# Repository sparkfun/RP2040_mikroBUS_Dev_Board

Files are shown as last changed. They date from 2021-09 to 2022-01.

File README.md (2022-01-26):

SparkFun RP2040 mikroBUS™ Development Board
========================================

SparkFun RP2040 mikroBUS™ Development Board (https://www.sparkfun.com/products/18721)

[*SparkFun RP2040 mikroBUS™ Development Board (DEV-18721)*](https://www.sparkfun.com/products/18721)

The SparkFun RP2040 mikroBUS™ development board is a low-cost, high performance board with flexible digital interfaces featuring the Raspberry Pi Foundation's RP2040 microcontroller. Besides the Thing Plus or *Feather* footprint (with 18 GPIO pins), the board also includes an SD card slot, 16MB (128Mbit) flash memory, a JST single cell battery connector (with a charging circuit and fuel gauge sensor), an addressable WS2812 RGB LED, JTAG PTH pins, a mikroBUS™ socket, and our signature Qwiic connector.

_The RP2040 is supported with both C/C++ and MicroPython cross-platform development environments, including easy access to runtime debugging. It has UF2 boot and floating-point routines baked into the chip. While the chip has a large amount of internal RAM, the board includes an additional 16MB of external QSPI flash memory to store program code._

_The [mikroBUS™ standard](https://www.mikroe.com/mikrobus) was developed by [MikroElektronika](https://www.mikroe.com/). Similar to our [Qwiic](https://www.sparkfun.com/qwiic) and [MicroMod](https://www.sparkfun.com/micromod) interfaces, mikroBUS™ provides a standardized connection for add-on [Click boards™](https://www.mikroe.com/click-boards) to be hooked up to a microcontroller based development board._

Repository Contents
-------------------

* **/Documentation** - Data sheets, additional product information
* **/Hardware** - Eagle design files (.brd, .sch)

Documentation
--------------

* **[Hookup Guide](https://learn.sparkfun.com/tutorials/2004)** - SparkFun RP2040 mikroBUS™ Development Board
* **[Raspberry Pi RP2040 Datasheet](https://datasheets.raspberrypi.org/rp2040/rp2040_datasheet.pdf)** - Datasheet for the RP2040
* **[SparkFun Graphical Datasheets](https://github.com/sparkfun/Graphical_Datasheets)** - Graphical datasheets for various SparkFun products.

Product Versions
----------------
* [DEV-18721](https://www.sparkfun.com/products/18721) -  initial release

License Information
-------------------

This product is _**open source**_! 

Please review the LICENSE.md file for license information. 

If you have any questions or concerns on licensing, please contact technical support on our [SparkFun forums](https://forum.sparkfun.com/viewforum.php?f=152).

Distributed as-is; no warranty is given.

- Your friends at SparkFun.

_<COLLABORATION CREDIT>_

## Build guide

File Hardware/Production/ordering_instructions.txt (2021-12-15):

panel size, 169x108mm
PCB thickness, 1.6mm
number of layers, 4
soldermask color, Red
silkscreen color, White
oz copper, 1oz
finish, HASL lead free
stencils, top+bottom
pcs per panel, 5
min trace width, 0.1016mm / 0.0040in
min drill size, 0.2000mm / 0.0079in
filename to layer stackup 1/2/3/4: GTL, GL2, GL3, GBL

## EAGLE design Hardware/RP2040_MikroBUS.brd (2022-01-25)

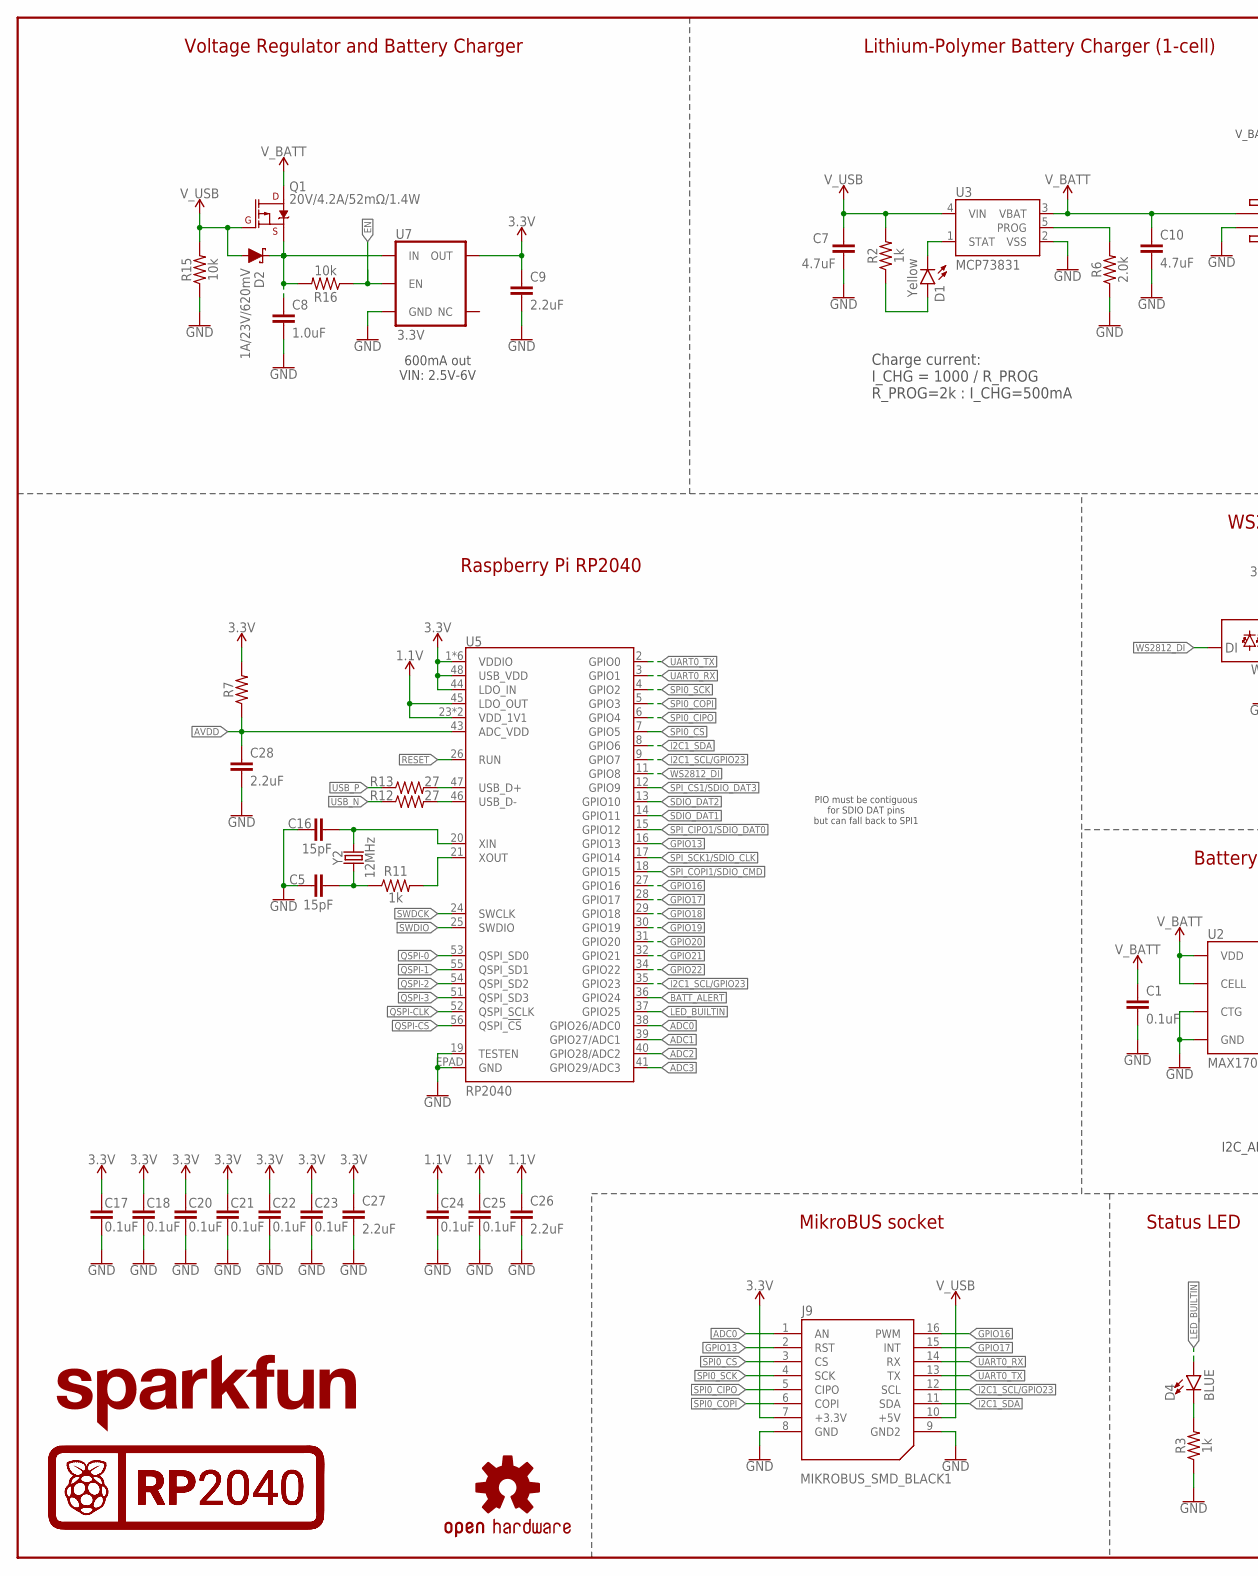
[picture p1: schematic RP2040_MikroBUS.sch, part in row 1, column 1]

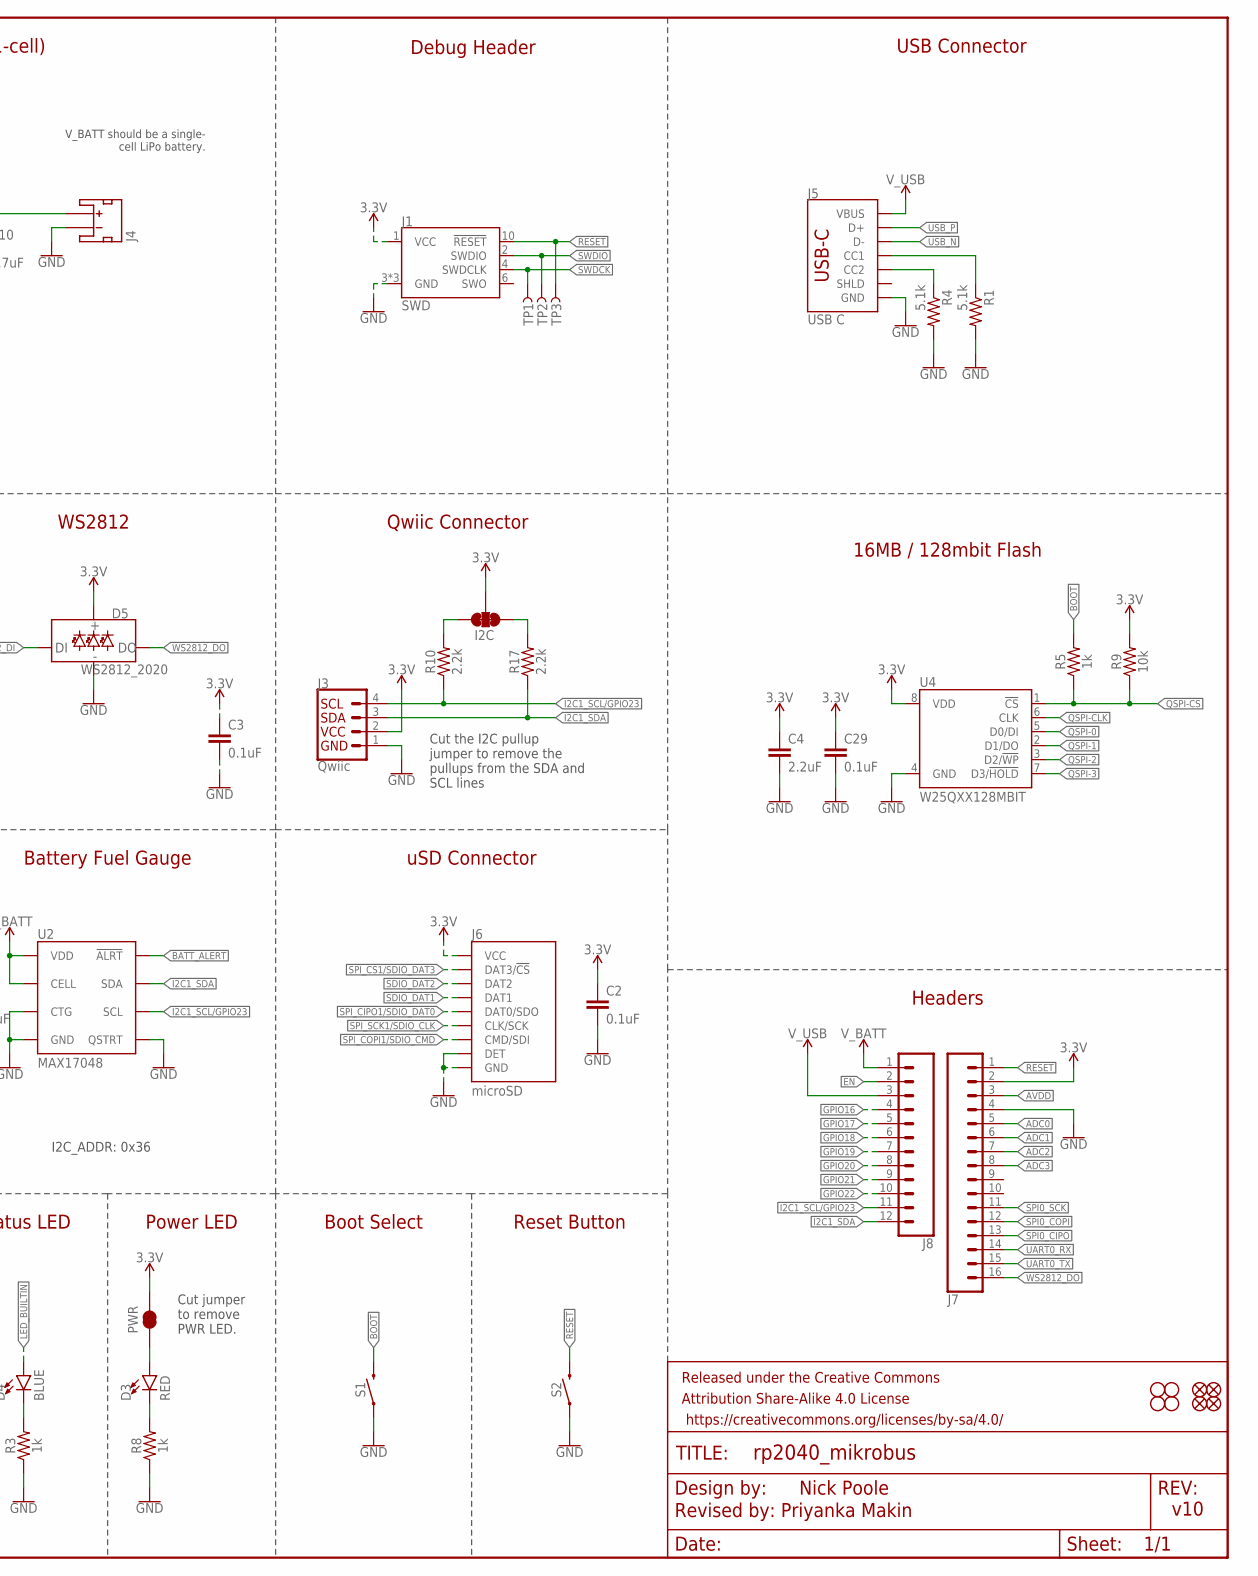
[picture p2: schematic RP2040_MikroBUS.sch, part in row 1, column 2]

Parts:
C1, C2, C3, C17, C18, C20, C21, C22, C23, C24, C25, C29: 0.1uF; 0402-TIGHT
C4, C9, C26, C27, C28: 2.2uF; 0402-TIGHT
C5, C16: 15pF; 0402-TIGHT
C7, C10: 4.7uF; 0402-TIGHT
C8: 1.0uF; 0402-TIGHT
D1: Yellow; LED-0603
D2: 1A/23V/620mV; SOD-323
D3: RED; LED-0603
D4: BLUE; LED-0603
D5: WS2812_2020; WS2812-2020
FD1, FD2, FD3, FD4: FIDUCIALUFIDUCIAL; FIDUCIAL-MICRO
FRAME1: FRAME-LEDGER; CREATIVE_COMMONS
H1, H2, H3, H4: STAND-OFF
I2C: JUMPER-SMT_3_2-NC_TRACE_SILK; SMT-JUMPER_3_2-NC_TRACE_SILK
J1: SWD; 2X5-PTH-1.27MM
J3: Qwiic; JST04_1MM_RA
J4: JST_2MM_MALE; JST-2-SMD
J5: USB C; USB-C-16P-4LAYER-ISOLATED
J6: microSD; MICROSD-EXTERNALPIN
J7: CONN_161X16_NO_SILK; 1X16_NO_SILK
J8: CONN_12NO_SILK; 1X12_NO_SILK
J9: MIKROBUS_SMD_BLACK1; MIKROBUS_SMD_BLACK
LOGO1: OSHW-LOGOS; OSHW-LOGO-S
LOGO2: SFE_LOGO_NAME.1_INCH; SFE_LOGO_NAME_.1
PWR: JUMPER-SMT_2_NC_TRACE_SILK; SMT-JUMPER_2_NC_TRACE_SILK
Q1: 20V/4.2A/52mΩ/1.4W; SOT23-3
R1, R4: 5.1k; 0402-TIGHT
R2, R3, R5, R8, R11: 1k; 0402-TIGHT
R6: 2.0k; 0603
R7: 200OHM-0402T-1/16W-1%; 0402-TIGHT
R9, R15, R16: 10k; 0402-TIGHT
R10, R17: 2.2k; 0402-TIGHT
R12, R13: 27; 0402-TIGHT
S1, S2: MOMENTARY-SWITCH-SPST-SMD-5.2MM-TALL; TACTILE_SWITCH_SMD_5.2MM
TP1, TP2, TP3: TEST-POINT3X4; PAD.03X.04
U2: MAX17048; DFN-8
U3: MCP73831; SOT23-5
U4: W25QXX128MBIT; WSON-8-6X5-SKINNY_CENTERPAD
U5: RP2040; QFN-56
U7: 3.3V; SOT23-5
U$17, U$73: RASPI_RP2040_LOGO_10MM
Y2: 12MHz; CRYSTAL-SMD-2X2.5MM

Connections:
1.1V: C24.1, C25.1, C26.1, U5.23 (VDD_1V1), U5.45 (LDO_OUT), U5.50 (VDD_1V1)
3.3V: C2.1, C3.1, C4.1, C9.1, C17.1, C18.1, C20.1, C21.1, C22.1, C23.1, C27.1, C29.1, D5.VCC, I2C.2, J1.1 (VCC), J3.2, J6.4 (VCC), J7.2, J9.7 (+3.3V), PWR.2, R7.2, R9.2, U4.8 (VDD), U5.1 (VDDIO), U5.10 (VDDIO), U5.22 (VDDIO), U5.33 (VDDIO), U5.42 (VDDIO), U5.44 (LDO_IN), U5.48 (USB_VDD), U5.49 (VDDIO), U7.5 (OUT)
!BATT_ALERT!: U2.5 (!ALRT), U5.36 (GPIO24)
!BOOT!: R5.2, S1.3 (2)
!QSPI-CS!: R5.1, R9.1, U4.1 (!CS!), U5.56 (QSPI_!CS!)
!RESET!: J1.10 (!RESET), J7.1, S2.3 (2), TP3.1, U5.26 (RUN)
!SPI0_CS!: J9.3 (CS), U5.7 (GPIO5)
ADC0: J7.5, J9.1 (AN), U5.38 (GPIO26/ADC0)
ADC1: J7.6, U5.39 (GPIO27/ADC1)
ADC2: J7.7, U5.40 (GPIO28/ADC2)
ADC3: J7.8, U5.41 (GPIO29/ADC3)
AVDD: C28.1, J7.3, R7.1, U5.43 (ADC_VDD)
EN: J8.2, R16.1, U7.3 (EN)
GND: C1.2, C2.2, C3.2, C4.2, C5.1, C7.2, C8.2, C9.2, C10.2, C16.1, C17.2, C18.2, C20.2, C21.2, C22.2, C23.2, C24.2, C25.2, C26.2, C27.2, C28.2, C29.2, D5.GND, J1.3 (GND), J1.5 (GND), J1.9 (GND), J3.1, J4.1 (-), J5.GND, J5.GND2 (GND), J6.6 (GND), J6.9 (DET), J6.10 (GND), J6.11 (GND), J6.12 (GND), J6.13 (GND), J7.4, J9.8 (GND), J9.9 (GND2), R1.2, R3.1, R4.2, R6.1, R8.1, R15.1, S1.1, S2.1, U2.1 (CTG), U2.4 (GND), U2.6 (QSTRT), U2.9 (GND), U3.2 (VSS), U4.4 (GND), U5.19 (TESTEN), U5.EPAD (GND), U7.2 (GND)
GPIO13: J9.2 (RST), U5.16 (GPIO13)
GPIO16: J8.4, J9.16 (PWM), U5.27 (GPIO16)
GPIO17: J8.5, J9.15 (INT), U5.28 (GPIO17)
GPIO18: J8.6, U5.29 (GPIO18)
GPIO19: J8.7, U5.30 (GPIO19)
GPIO20: J8.8, U5.31 (GPIO20)
GPIO21: J8.9, U5.32 (GPIO21)
GPIO22: J8.10, U5.34 (GPIO22)
I2C1_SCL/GPIO23: J3.4, J8.11, J9.12 (SCL), R10.1, U2.7 (SCL), U5.9 (GPIO7), U5.35 (GPIO23)
I2C1_SDA: J3.3, J8.12, J9.11 (SDA), R17.1, U2.8 (SDA), U5.8 (GPIO6)
LED_BUILTIN: D4.A, U5.37 (GPIO25)
unnamed: D4.C, R3.2
unnamed: I2C.3, R10.2
unnamed: I2C.1, R17.2
unnamed: R11.2, U5.21 (XOUT)
unnamed: C16.2, U5.20 (XIN), Y2.P3 (2)
unnamed: C5.2, R11.1, Y2.P1 (1)
unnamed: D3.C, R8.2
unnamed: D1.C, U3.1 (STAT)
unnamed: D3.A, PWR.1
unnamed: J5.A5 (CC1), R1.1
unnamed: J5.B5 (CC2), R4.1
unnamed: R6.2, U3.5 (PROG)
unnamed: C8.1, D2.C, Q1.2 (S), R16.2, U7.1 (IN)
unnamed: D1.A, R2.1
QSPI-0: U4.5 (D0/DI), U5.53 (QSPI_SD0)
QSPI-1: U4.2 (D1/DO), U5.55 (QSPI_SD1)
QSPI-2: U4.3 (D2/!WP!), U5.54 (QSPI_SD2)
QSPI-3: U4.7 (D3/!HOLD!), U5.51 (QSPI_SD3)
QSPI-CLK: U4.6 (CLK), U5.52 (QSPI_SCLK)
SDIO_DAT1: J6.8 (DAT1), U5.14 (GPIO11)
SDIO_DAT2: J6.1 (DAT2), U5.13 (GPIO10)
SPI0_CIPO: J7.13, J9.5 (CIPO), U5.6 (GPIO4)
SPI0_COPI: J7.12, J9.6 (COPI), U5.5 (GPIO3)
SPI0_SCK: J7.11, J9.4 (SCK), U5.4 (GPIO2)
SPI_!CS1!/SDIO_DAT3: J6.2 (DAT3/!CS!), U5.12 (GPIO9)
SPI_CIPO1/SDIO_DAT0: J6.7 (DAT0/SDO), U5.15 (GPIO12)
SPI_COPI1/SDIO_CMD: J6.3 (CMD/SDI), U5.18 (GPIO15)
SPI_SCK1/SDIO_CLK: J6.5 (CLK/SCK), U5.17 (GPIO14)
SWDCK: J1.4 (SWDCLK), TP1.1, U5.24 (SWCLK)
SWDIO: J1.2 (SWDIO), TP2.1, U5.25 (SWDIO)
UART0_RX: J7.14, J9.14 (RX), U5.3 (GPIO1)
UART0_TX: J7.15, J9.13 (TX), U5.2 (GPIO0)
USB_F_N: R12.2, U5.46 (USB_D-)
USB_F_P: R13.2, U5.47 (USB_D+)
USB_N: J5.A7 (D-), J5.B7 (D-), R12.1
USB_P: J5.A6 (D+), J5.B6 (D+), R13.1
V_BATT: C1.1, C10.1, J4.2 (+), J8.1, Q1.3 (D), U2.2 (CELL), U2.3 (VDD), U3.3 (VBAT)
V_USB: C7.1, D2.A, J5.VBUS1 (VBUS), J5.VBUS2 (VBUS), J8.3, J9.10 (+5V), Q1.1 (G), R2.2, R15.2, U3.4 (VIN)
WS2812_DI: D5.DI, U5.11 (GPIO8)
WS2812_DO: D5.DO, J7.16

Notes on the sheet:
V_BATT should be a single- cell LiPo battery.
Charge current: I_CHG = 1000 / R_PROG R_PROG=2k : I_CHG=500mA
Voltage Regulator and Battery Charger
Lithium-Polymer Battery Charger (1-cell)
600mA out VIN: 2.5V-6V
Reset Button
Status LED
Headers
v10
Qwiic Connector
USB Connector
Cut the I2C pullup jumper to remove the pullups from the SDA and SCL lines
Raspberry Pi RP2040
PIO must be contiguous for SDIO DAT pins but can fall back to SPI1
16MB / 128mbit Flash
uSD Connector
Battery Fuel Gauge
WS2812
I2C_ADDR: 0x36
Boot Select
Debug Header
Power LED
MikroBUS socket
Nick Poole
Revised by: Priyanka Makin
Cut jumper to remove PWR LED.

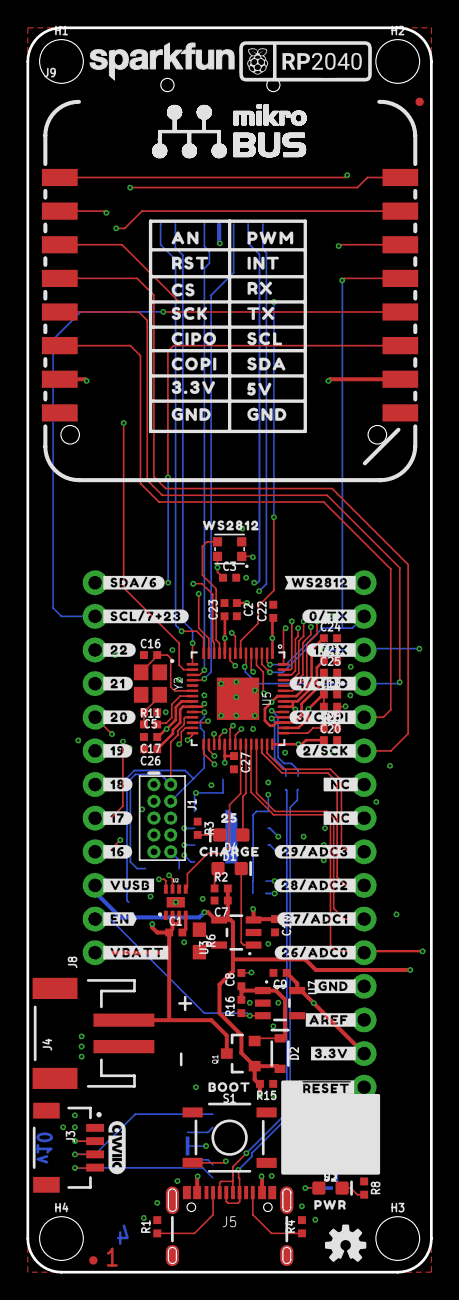
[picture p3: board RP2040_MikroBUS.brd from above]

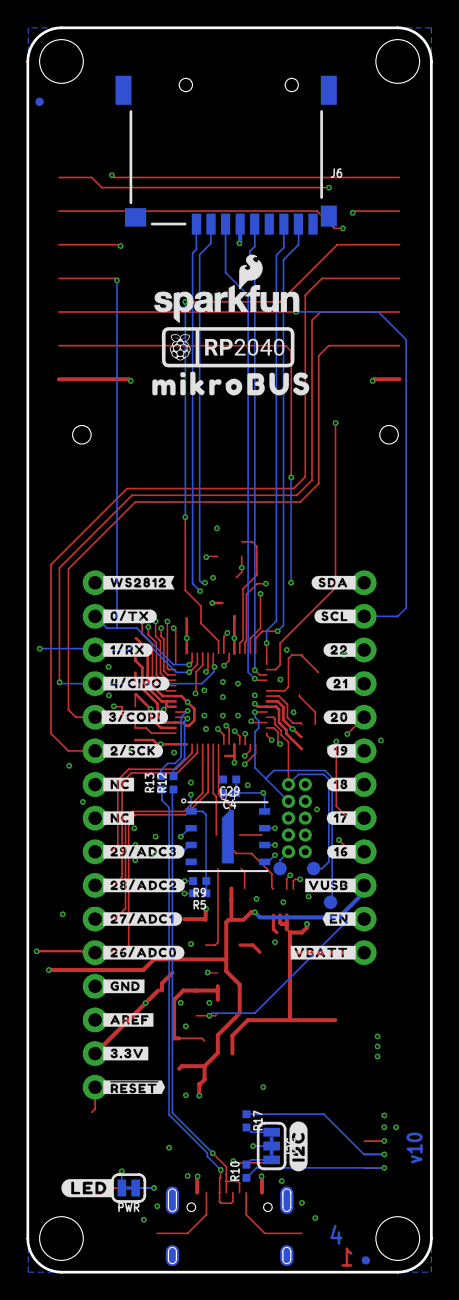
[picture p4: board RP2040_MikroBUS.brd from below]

Board: 4 copper layers, 30.5 x 94.0 mm, 161 parts (50 on the bottom side), 65 nets.

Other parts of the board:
U$1: #_16#0
U$2: #_17#0
U$3: #_18#0
U$4: #_19#0
U$5: #_20#0
U$6: #_21#0
U$7: #_22#0
U$8: #_SCL#7#23#0
U$9: #_SDA#6#0
U$10: #WS2812_#0
U$11: #0#TX_#0
U$12: #1#RX_#0
U$13: #4#CIPO_#0
U$14: #3#COPI_#0
U$15: #2#SCK_#0
U$16: PWR0
U$18: #29#ADC3_#0
U$19: #28#ADC2_#0
U$20: #27#ADC1_#0
U$21: #26#ADC0_#0
U$22: #_VUSB#0
U$23: #_EN#0
U$24: #_VBATT#0
U$25: #GND_#0
U$26: #AREF_#0
U$27: #3#3V_#0
U$28: ##RESET##0
U$29: AN0
U$30: WS28120
U$31: ORDERING_INSTRUCTIONS
U$32: SFE_LOGO_NAME_FLAME_.1
U$33: #SCL_#0
U$34: #SDA_#0
U$35: #_#RESET##0
U$36: #_3#3V#0
U$37: #_AREF#0
U$38: #_GND#0
U$39: #_26#ADC0#0
U$40: #_27#ADC1#0
U$41: #_28#ADC2#0
U$42: #_29#ADC3#0
U$43: #LED#0
U$44: RST0
U$45: CS0
U$47, U$48: #_NC_#0
U$49: #_2#SCK#0
U$50: #_3#COPI#0
U$51: #_4#CIPO#0
U$52: #_1#RX#0
U$53: #_0#TX#0
U$54: 250
U$55: CHARGE0
U$56: BOOT0
U$57: #22_#0
U$58: #21_#0
U$59: #20_#0
U$60: CIPO0
U$61: #19_#0
U$62: #18_#0
U$63: #17_#0
U$64: QWIIC_4MM
U$65: #16_#0
U$66: #VUSB_#0
U$67: #EN_#0
U$68: #VBATT_#0
U$69, U$70: #_NC#0
U$71: #_WS2812#0
U$72: #I2C#0
U$74: SCK0
U$75: COPI0
U$76: 3#3V0
U$77, U$78: GND0
U$79: 5V0
U$80: SDA0
U$81: SCL0
U$82: TX0
U$83: RX0
U$84: INT0
U$85: PWM0
U$88: MIKROBUS0

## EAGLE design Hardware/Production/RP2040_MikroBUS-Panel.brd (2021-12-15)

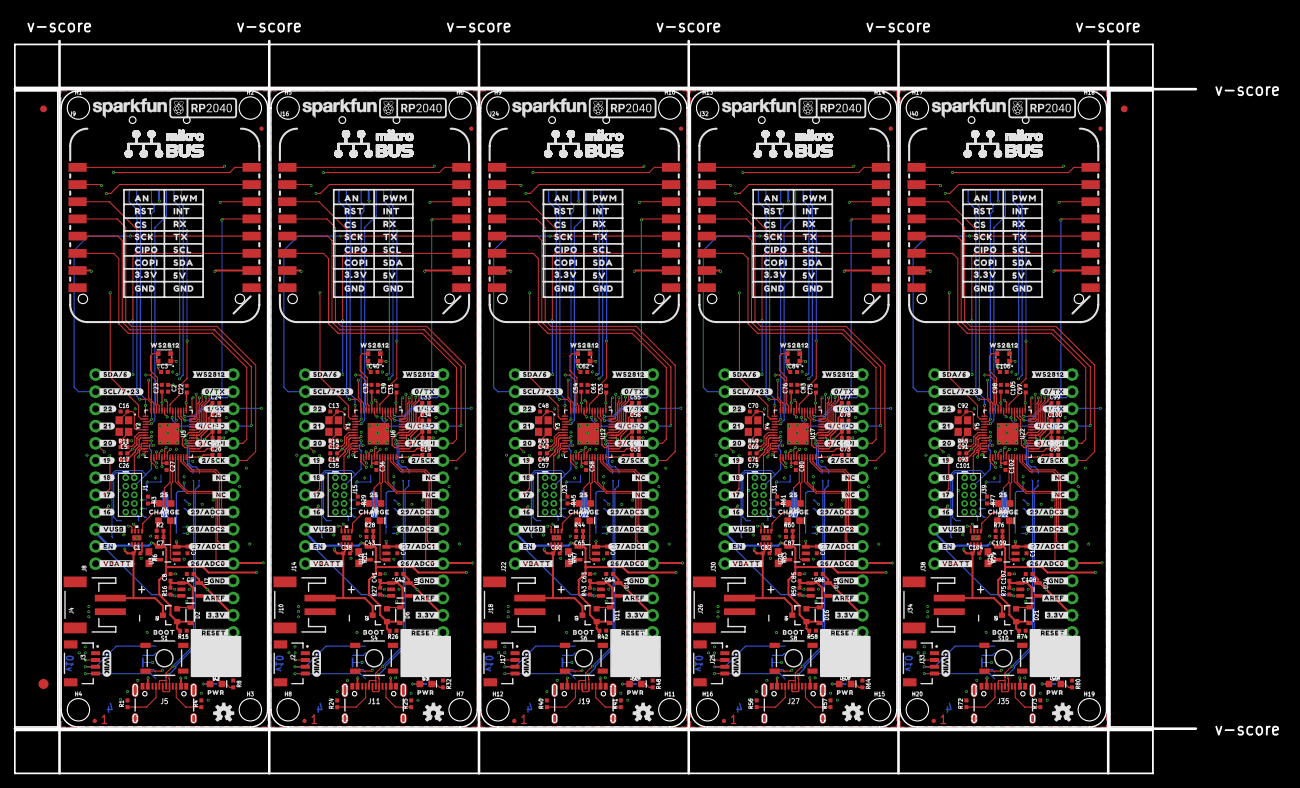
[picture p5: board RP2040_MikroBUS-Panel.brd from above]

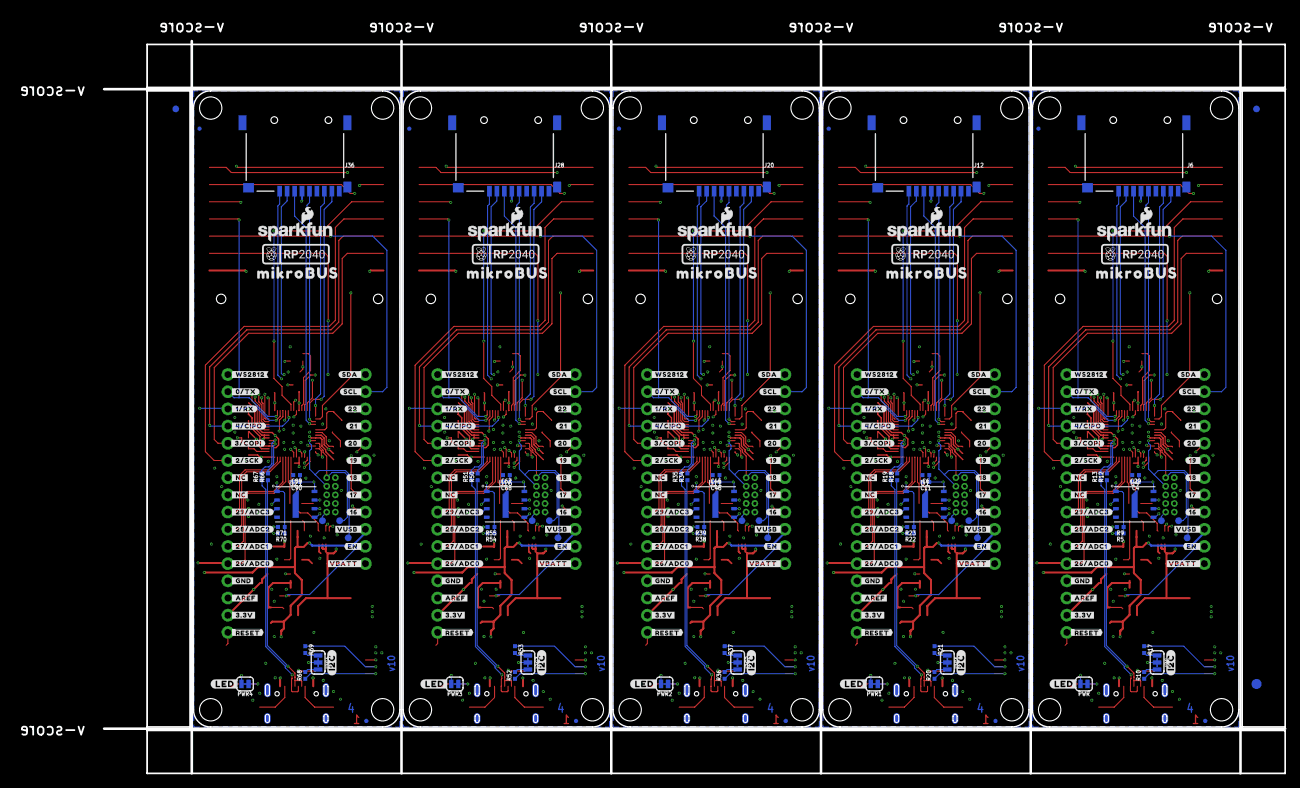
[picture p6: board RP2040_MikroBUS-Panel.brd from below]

Board: 4 copper layers, 174.5 x 108.2 mm, 801 parts (253 on the bottom side), 325 nets.

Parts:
C1, C2, C3, C6, C14, C15, C17, C18, C19, C20, C21, C22, C23, C24, C25, C29, C30, C31, C32, C33, C34, C38, C39, C40, C45, C49, C50, C51, C52, C53, C54, C55, C56, C60, C61, C62, C67, C71, C72, C73, C74, C75, C76, C77, C78, C82, C83, C84, C89, C93, C94, C95, C96, C97, C98, C99, C100, C104, C105, C106: 0.1uF; 0402-TIGHT
C4, C9, C11, C26, C27, C28, C35, C36, C37, C42, C46, C57, C58, C59, C64, C68, C79, C80, C81, C86, C90, C101, C102, C103, C108: 2.2uF; 0402-TIGHT
C5, C12, C13, C16, C47, C48, C69, C70, C91, C92: 15pF; 0402-TIGHT
C7, C10, C43, C44, C65, C66, C87, C88, C109, C110: 4.7uF; 0402-TIGHT
C8, C41, C63, C85, C107: 1.0uF; 0402-TIGHT
D1, D7, D12, D17, D22: Yellow; LED-0603
D2, D6, D11, D16, D21: 1A/23V/620mV; SOD-323
D3, D9, D14, D19, D24: RED; LED-0603
D4, D8, D13, D18, D23: BLUE; LED-0603
D5, D10, D15, D20, D25: WS2812_2020; WS2812-2020
E$1, E$2, E$3, E$4: FIDUCIAL-1X2
E$5, E$6: FIDUCIAL-1.5X3
FD1, FD2, FD3, FD4, FD5, FD6, FD7, FD8, FD9, FD10, FD11, FD12, FD13, FD14, FD15, FD16, FD17, FD18, FD19, FD20: FIDUCIALUFIDUCIAL; FIDUCIAL-MICRO
H1, H2, H3, H4, H5, H6, H7, H8, H9, H10, H11, H12, H13, H14, H15, H16, H17, H18, H19, H20: STAND-OFF
I2C, I2C1, I2C2, I2C3, I2C4: JUMPER-SMT_3_2-NC_TRACE_SILK; SMT-JUMPER_3_2-NC_TRACE_SILK
J1, J15, J23, J31, J39: SWD; 2X5-PTH-1.27MM
J2, J3, J17, J25, J33: Qwiic; JST04_1MM_RA
J4, J10, J18, J26, J34: JST-2-SMD
J5, J11, J19, J27, J35: USB C; USB-C-16P-4LAYER-ISOLATED
J6, J12, J20, J28, J36: microSD; MICROSD-EXTERNALPIN
J7, J13, J21, J29, J37: 1X16_NO_SILK
J8, J14, J22, J30, J38: 1X12_NO_SILK
J9, J16, J24, J32, J40: MIKROBUS_SMD_BLACK1; MIKROBUS_SMD_BLACK
LOGO1, LOGO3, LOGO5, LOGO7, LOGO9: OSHW-LOGOS; OSHW-LOGO-S
LOGO2, LOGO4, LOGO6, LOGO8, LOGO10: SFE_LOGO_NAME.1_INCH; SFE_LOGO_NAME_.1
PWR, PWR1, PWR2, PWR3, PWR4: JUMPER-SMT_2_NC_TRACE_SILK; SMT-JUMPER_2_NC_TRACE_SILK
Q1, Q2, Q3, Q4, Q5: 20V/4.2A/52mΩ/1.4W; SOT23-3
R1, R4, R24, R25, R40, R41, R56, R57, R72, R73: 5.1k; 0402-TIGHT
R2, R3, R5, R8, R11, R14, R22, R28, R29, R32, R33, R38, R44, R45, R48, R49, R54, R60, R61, R64, R65, R70, R76, R77, R80: 1k; 0402-TIGHT
R6, R31, R47, R63, R79: 2.0k; 0603
R7, R30, R46, R62, R78: 200OHM-0402T-1/16W-1%; 0402-TIGHT
R9, R15, R16, R23, R26, R27, R39, R42, R43, R55, R58, R59, R71, R74, R75: 10k; 0402-TIGHT
R10, R17, R20, R21, R36, R37, R52, R53, R68, R69: 2.2k; 0402-TIGHT
R12, R13, R18, R19, R34, R35, R50, R51, R66, R67: 27; 0402-TIGHT
S1, S2, S3, S4, S5, S6, S7, S8, S9, S10: MOMENTARY-SWITCH-SPST-SMD-5.2MM-TALL; TACTILE_SWITCH_SMD_5.2MM
TP1, TP2, TP3, TP4, TP5, TP6, TP7, TP8, TP9, TP10, TP11, TP12, TP13, TP14, TP15: TEST-POINT3X4; PAD.03X.04
U1, U4, U11, U16, U21: W25QXX128MBIT; WSON-8-6X5-SKINNY_CENTERPAD
U2, U8, U13, U18, U23: MAX17048; DFN-8
U3, U10, U15, U20, U25: MCP73831; SOT23-5
U5, U6, U12, U17, U22: RP2040; QFN-56
U7, U9, U14, U19, U24: 3.3V; SOT23-5
U$1, U$31, U$169, U$253, U$337: #_16#0
U$2, U$46, U$170, U$254, U$338: #_17#0
U$3, U$86, U$171, U$255, U$339: #_18#0
U$4, U$87, U$172, U$256, U$340: #_19#0
U$5, U$89, U$173, U$257, U$341: #_20#0
U$6, U$90, U$174, U$258, U$342: #_21#0
U$7, U$91, U$175, U$259, U$343: #_22#0
U$8, U$98, U$182, U$266, U$350: #_SCL#7#23#0
U$9, U$99, U$183, U$267, U$351: #_SDA#6#0
U$10, U$92, U$176, U$260, U$344: #WS2812_#0
U$11, U$93, U$177, U$261, U$345: #0#TX_#0
U$12, U$94, U$178, U$262, U$346: #1#RX_#0
U$13, U$95, U$179, U$263, U$347: #4#CIPO_#0
U$14, U$96, U$180, U$264, U$348: #3#COPI_#0
U$15, U$97, U$181, U$265, U$349: #2#SCK_#0
U$16, U$138, U$222, U$306, U$390: PWR0
U$17, U$73, U$148, U$149, U$232, U$233, U$316, U$317, U$400, U$401: RASPI_RP2040_LOGO_10MM
U$18, U$100, U$184, U$268, U$352: #29#ADC3_#0
U$19, U$101, U$185, U$269, U$353: #28#ADC2_#0
U$20, U$102, U$186, U$270, U$354: #27#ADC1_#0
U$21, U$103, U$187, U$271, U$355: #26#ADC0_#0
U$22, U$104, U$188, U$272, U$356: #_VUSB#0
U$23, U$105, U$189, U$273, U$357: #_EN#0
U$24, U$106, U$190, U$274, U$358: #_VBATT#0
U$25, U$107, U$191, U$275, U$359: #GND_#0
U$26, U$108, U$192, U$276, U$360: #AREF_#0
U$27, U$109, U$193, U$277, U$361: #3#3V_#0
U$28, U$110, U$194, U$278, U$362: ##RESET##0
U$29, U$151, U$235, U$319, U$403: AN0
U$30, U$150, U$234, U$318, U$402: WS28120
U$32, U$112, U$196, U$280, U$364: SFE_LOGO_NAME_FLAME_.1
U$33, U$126, U$210, U$294, U$378: #SCL_#0
U$34, U$127, U$211, U$295, U$379: #SDA_#0
U$35, U$128, U$212, U$296, U$380: #_#RESET##0
U$36, U$129, U$213, U$297, U$381: #_3#3V#0
U$37, U$130, U$214, U$298, U$382: #_AREF#0
U$38, U$131, U$215, U$299, U$383: #_GND#0
U$39, U$132, U$216, U$300, U$384: #_26#ADC0#0
U$40, U$133, U$217, U$301, U$385: #_27#ADC1#0
U$41, U$134, U$218, U$302, U$386: #_28#ADC2#0
U$42, U$135, U$219, U$303, U$387: #_29#ADC3#0
U$43, U$168, U$252, U$336, U$420: #LED#0
U$44, U$152, U$236, U$320, U$404: RST0
U$45, U$153, U$237, U$321, U$405: CS0
U$47, U$48, U$139, U$140, U$223, U$224, U$307, U$308, U$391, U$392: #_NC_#0
U$49, U$141, U$225, U$309, U$393: #_2#SCK#0
U$50, U$142, U$226, U$310, U$394: #_3#COPI#0
U$51, U$143, U$227, U$311, U$395: #_4#CIPO#0
U$52, U$144, U$228, U$312, U$396: #_1#RX#0
U$53, U$145, U$229, U$313, U$397: #_0#TX#0
U$54, U$113, U$197, U$281, U$365: 250
U$55, U$114, U$198, U$282, U$366: CHARGE0
U$56, U$115, U$199, U$283, U$367: BOOT0
U$57, U$116, U$200, U$284, U$368: #22_#0
U$58, U$117, U$201, U$285, U$369: #21_#0
U$59, U$118, U$202, U$286, U$370: #20_#0
U$60, U$154, U$238, U$322, U$406: CIPO0
U$61, U$119, U$203, U$287, U$371: #19_#0
U$62, U$120, U$204, U$288, U$372: #18_#0
U$63, U$121, U$205, U$289, U$373: #17_#0
U$64, U$111, U$195, U$279, U$363: QWIIC_4MM
U$65, U$122, U$206, U$290, U$374: #16_#0
U$66, U$123, U$207, U$291, U$375: #VUSB_#0
U$67, U$124, U$208, U$292, U$376: #EN_#0
U$68, U$125, U$209, U$293, U$377: #VBATT_#0
U$69, U$70, U$136, U$137, U$220, U$221, U$304, U$305, U$388, U$389: #_NC#0
U$71, U$146, U$230, U$314, U$398: #_WS2812#0
U$72, U$147, U$231, U$315, U$399: #I2C#0
U$74, U$155, U$239, U$323, U$407: SCK0
U$75, U$156, U$240, U$324, U$408: COPI0
U$76, U$157, U$241, U$325, U$409: 3#3V0
U$77, U$78, U$158, U$159, U$242, U$243, U$326, U$327, U$410, U$411: GND0
U$79, U$160, U$244, U$328, U$412: 5V0
U$80, U$161, U$245, U$329, U$413: SDA0
U$81, U$162, U$246, U$330, U$414: SCL0
U$82, U$163, U$247, U$331, U$415: TX0
U$83, U$164, U$248, U$332, U$416: RX0
U$84, U$165, U$249, U$333, U$417: INT0
U$85, U$166, U$250, U$334, U$418: PWM0
U$88, U$167, U$251, U$335, U$419: MIKROBUS0
Y1, Y2, Y3, Y4, Y5: 12MHz; CRYSTAL-SMD-2X2.5MM

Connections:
1.1V: C24.1, C25.1, C26.1, U5.23, U5.45, U5.50
1.1V1: C33.1, C34.1, C35.1, U6.23, U6.45, U6.50
1.1V2: C55.1, C56.1, C57.1, U12.23, U12.45, U12.50
1.1V3: C77.1, C78.1, C79.1, U17.23, U17.45, U17.50
1.1V4: C99.1, C100.1, C101.1, U22.23, U22.45, U22.50
3.3V: C2.1, C3.1, C4.1, C9.1, C17.1, C18.1, C20.1, C21.1, C22.1, C23.1, C27.1, C29.1, D5.VCC, I2C.2, J1.1, J3.2, J6.4, J7.2, J9.7, PWR.2, R7.2, R9.2, U4.8, U5.1, U5.10, U5.22, U5.33, U5.42, U5.44, U5.48, U5.49, U7.5
3.3V1: C6.1, C11.1, C14.1, C15.1, C19.1, C30.1, C31.1, C32.1, C36.1, C39.1, C40.1, C42.1, D10.VCC, I2C1.2, J2.2, J12.4, J13.2, J15.1, J16.7, PWR1.2, R23.2, R30.2, U1.8, U6.1, U6.10, U6.22, U6.33, U6.42, U6.44, U6.48, U6.49, U9.5
3.3V2: C45.1, C46.1, C49.1, C50.1, C51.1, C52.1, C53.1, C54.1, C58.1, C61.1, C62.1, C64.1, D15.VCC, I2C2.2, J17.2, J20.4, J21.2, J23.1, J24.7, PWR2.2, R39.2, R46.2, U11.8, U12.1, U12.10, U12.22, U12.33, U12.42, U12.44, U12.48, U12.49, U14.5
3.3V3: C67.1, C68.1, C71.1, C72.1, C73.1, C74.1, C75.1, C76.1, C80.1, C83.1, C84.1, C86.1, D20.VCC, I2C3.2, J25.2, J28.4, J29.2, J31.1, J32.7, PWR3.2, R55.2, R62.2, U16.8, U17.1, U17.10, U17.22, U17.33, U17.42, U17.44, U17.48, U17.49, U19.5
3.3V4: C89.1, C90.1, C93.1, C94.1, C95.1, C96.1, C97.1, C98.1, C102.1, C105.1, C106.1, C108.1, D25.VCC, I2C4.2, J33.2, J36.4, J37.2, J39.1, J40.7, PWR4.2, R71.2, R78.2, U21.8, U22.1, U22.10, U22.22, U22.33, U22.42, U22.44, U22.48, U22.49, U24.5
!BATT_ALERT!: U2.5, U5.36
!BATT_ALERT!1: U6.36, U8.5
!BATT_ALERT!2: U12.36, U13.5
!BATT_ALERT!3: U17.36, U18.5
!BATT_ALERT!4: U22.36, U23.5
!BOOT!: R5.2, S1.3
!BOOT!1: R22.2, S4.3
!BOOT!2: R38.2, S6.3
!BOOT!3: R54.2, S8.3
!BOOT!4: R70.2, S10.3
!QSPI-CS!: R5.1, R9.1, U4.1, U5.56
!QSPI-CS!1: R22.1, R23.1, U1.1, U6.56
!QSPI-CS!2: R38.1, R39.1, U11.1, U12.56
!QSPI-CS!3: R54.1, R55.1, U16.1, U17.56
!QSPI-CS!4: R70.1, R71.1, U21.1, U22.56
!RESET!: J1.10, J7.1, S2.3, TP3.1, U5.26
!RESET!1: J13.1, J15.10, S3.3, TP6.1, U6.26
!RESET!2: J21.1, J23.10, S5.3, TP9.1, U12.26
!RESET!3: J29.1, J31.10, S7.3, TP12.1, U17.26
!RESET!4: J37.1, J39.10, S9.3, TP15.1, U22.26
!SPI0_CS!: J9.3, U5.7
!SPI0_CS!1: J16.3, U6.7
!SPI0_CS!2: J24.3, U12.7
!SPI0_CS!3: J32.3, U17.7
!SPI0_CS!4: J40.3, U22.7
ADC0: J7.5, J9.1, U5.38
ADC1: J7.6, U5.39
ADC2: J7.7, U5.40
ADC3: J7.8, U5.41
ADC4: J13.8, U6.41
ADC5: J13.5, J16.1, U6.38
ADC6: J13.6, U6.39
ADC7: J13.7, U6.40
ADC8: J21.8, U12.41
ADC9: J21.5, J24.1, U12.38
ADC10: J21.6, U12.39
ADC11: J21.7, U12.40
ADC12: J29.8, U17.41
ADC13: J29.5, J32.1, U17.38
ADC14: J29.6, U17.39
ADC15: J29.7, U17.40
ADC16: J37.8, U22.41
ADC17: J37.5, J40.1, U22.38
ADC18: J37.6, U22.39
ADC19: J37.7, U22.40
AVDD: C28.1, J7.3, R7.1, U5.43
AVDD1: C37.1, J13.3, R30.1, U6.43
AVDD2: C59.1, J21.3, R46.1, U12.43
AVDD3: C81.1, J29.3, R62.1, U17.43
AVDD4: C103.1, J37.3, R78.1, U22.43
EN: J8.2, R16.1, U7.3
EN1: J14.2, R27.1, U9.3
EN2: J22.2, R43.1, U14.3
EN3: J30.2, R59.1, U19.3
EN4: J38.2, R75.1, U24.3
GND: C1.2, C2.2, C3.2, C4.2, C5.1, C7.2, C8.2, C9.2, C10.2, C16.1, C17.2, C18.2, C20.2, C21.2, C22.2, C23.2, C24.2, C25.2, C26.2, C27.2, C28.2, C29.2, D5.GND, J1.3, J1.5, J1.9, J3.1, J4.1, J5.GND, J5.GND2, J6.6, J6.9, J6.10, J6.11, J6.12, J6.13, J7.4, J9.8, J9.9, R1.2, R3.1, R4.2, R6.1, R8.1, R15.1, S1.1, S2.1, U2.1, U2.4, U2.6, U2.9, U3.2, U4.4, U5.19, U5.EPAD, U7.2
GND1: C6.2, C11.2, C12.1, C13.1, C14.2, C15.2, C19.2, C30.2, C31.2, C32.2, C33.2, C34.2, C35.2, C36.2, C37.2, C38.2, C39.2, C40.2, C41.2, C42.2, C43.2, C44.2, D10.GND, J2.1, J10.1, J11.GND, J11.GND2, J12.6, J12.9, J12.10, J12.11, J12.12, J12.13, J13.4, J15.3, J15.5, J15.9, J16.8, J16.9, R24.2, R25.2, R26.1, R29.1, R31.1, R32.1, S3.1, S4.1, U1.4, U6.19, U6.EPAD, U8.1, U8.4, U8.6, U8.9, U9.2, U10.2
GND2: C45.2, C46.2, C47.1, C48.1, C49.2, C50.2, C51.2, C52.2, C53.2, C54.2, C55.2, C56.2, C57.2, C58.2, C59.2, C60.2, C61.2, C62.2, C63.2, C64.2, C65.2, C66.2, D15.GND, J17.1, J18.1, J19.GND, J19.GND2, J20.6, J20.9, J20.10, J20.11, J20.12, J20.13, J21.4, J23.3, J23.5, J23.9, J24.8, J24.9, R40.2, R41.2, R42.1, R45.1, R47.1, R48.1, S5.1, S6.1, U11.4, U12.19, U12.EPAD, U13.1, U13.4, U13.6, U13.9, U14.2, U15.2
GND3: C67.2, C68.2, C69.1, C70.1, C71.2, C72.2, C73.2, C74.2, C75.2, C76.2, C77.2, C78.2, C79.2, C80.2, C81.2, C82.2, C83.2, C84.2, C85.2, C86.2, C87.2, C88.2, D20.GND, J25.1, J26.1, J27.GND, J27.GND2, J28.6, J28.9, J28.10, J28.11, J28.12, J28.13, J29.4, J31.3, J31.5, J31.9, J32.8, J32.9, R56.2, R57.2, R58.1, R61.1, R63.1, R64.1, S7.1, S8.1, U16.4, U17.19, U17.EPAD, U18.1, U18.4, U18.6, U18.9, U19.2, U20.2
GND4: C89.2, C90.2, C91.1, C92.1, C93.2, C94.2, C95.2, C96.2, C97.2, C98.2, C99.2, C100.2, C101.2, C102.2, C103.2, C104.2, C105.2, C106.2, C107.2, C108.2, C109.2, C110.2, D25.GND, J33.1, J34.1, J35.GND, J35.GND2, J36.6, J36.9, J36.10, J36.11, J36.12, J36.13, J37.4, J39.3, J39.5, J39.9, J40.8, J40.9, R72.2, R73.2, R74.1, R77.1, R79.1, R80.1, S9.1, S10.1, U21.4, U22.19, U22.EPAD, U23.1, U23.4, U23.6, U23.9, U24.2, U25.2
GPIO1: J14.4, J16.16, U6.27
GPIO2: J14.5, J16.15, U6.28
GPIO3: J14.6, U6.29
GPIO4: J14.7, U6.30
GPIO5: J14.8, U6.31
GPIO6: J14.9, U6.32
GPIO7: J14.10, U6.34
GPIO8: J16.2, U6.16
GPIO9: J22.4, J24.16, U12.27
GPIO10: J22.5, J24.15, U12.28
GPIO11: J22.6, U12.29
GPIO12: J22.7, U12.30
GPIO13: J9.2, U5.16
GPIO14: J22.8, U12.31
GPIO15: J22.9, U12.32
GPIO16: J8.4, J9.16, U5.27
GPIO17: J8.5, J9.15, U5.28
GPIO18: J8.6, U5.29
GPIO19: J8.7, U5.30
GPIO20: J8.8, U5.31
GPIO21: J8.9, U5.32
GPIO22: J8.10, U5.34
GPIO23: J22.10, U12.34
GPIO24: J24.2, U12.16
GPIO25: J30.4, J32.16, U17.27
GPIO26: J30.5, J32.15, U17.28
GPIO27: J30.6, U17.29
GPIO28: J30.7, U17.30
GPIO29: J30.8, U17.31
GPIO30: J30.9, U17.32
GPIO31: J30.10, U17.34
GPIO32: J32.2, U17.16
GPIO33: J38.4, J40.16, U22.27
GPIO34: J38.5, J40.15, U22.28
GPIO35: J38.6, U22.29
GPIO36: J38.7, U22.30
GPIO37: J38.8, U22.31
GPIO38: J38.9, U22.32
GPIO39: J38.10, U22.34
GPIO40: J40.2, U22.16
I2C1_SCL/GPIO1: J2.4, J14.11, J16.12, R20.1, U6.9, U6.35, U8.7
I2C1_SCL/GPIO2: J17.4, J22.11, J24.12, R36.1, U12.9, U12.35, U13.7
I2C1_SCL/GPIO3: J25.4, J30.11, J32.12, R52.1, U17.9, U17.35, U18.7
I2C1_SCL/GPIO4: J33.4, J38.11, J40.12, R68.1, U22.9, U22.35, U23.7
I2C1_SCL/GPIO23: J3.4, J8.11, J9.12, R10.1, U2.7, U5.9, U5.35
I2C1_SDA: J3.3, J8.12, J9.11, R17.1, U2.8, U5.8
I2C1_SDA1: J2.3, J14.12, J16.11, R21.1, U6.8, U8.8
I2C1_SDA2: J17.3, J22.12, J24.11, R37.1, U12.8, U13.8
I2C1_SDA3: J25.3, J30.12, J32.11, R53.1, U17.8, U18.8
I2C1_SDA4: J33.3, J38.12, J40.11, R69.1, U22.8, U23.8
LED_BUILTIN: D4.A, U5.37
LED_BUILTIN1: D8.A, U6.37
LED_BUILTIN2: D13.A, U12.37
LED_BUILTIN3: D18.A, U17.37
LED_BUILTIN4: D23.A, U22.37
unnamed: D4.C, R3.2
unnamed: I2C.3, R10.2
unnamed: I2C.1, R17.2
unnamed: R11.2, U5.21
unnamed: C16.2, U5.20, Y2.P3
unnamed: C5.2, R11.1, Y2.P1
unnamed: D3.C, R8.2
unnamed: D7.C, U10.1
unnamed: D1.C, U3.1
unnamed: D3.A, PWR.1
unnamed: J5.A5, R1.1
unnamed: J5.B5, R4.1
unnamed: R31.2, U10.5
unnamed: R6.2, U3.5
unnamed: C8.1, D2.C, Q1.2, R16.2, U7.1
unnamed: D7.A, R28.1
unnamed: D1.A, R2.1
unnamed: D8.C, R29.2
unnamed: I2C1.3, R20.2
unnamed: I2C1.1, R21.2
unnamed: R14.2, U6.21
unnamed: C13.2, U6.20, Y1.P3
unnamed: C12.2, R14.1, Y1.P1
unnamed: J11.A5, R24.1
unnamed: J11.B5, R25.1
unnamed: C41.1, D6.C, Q2.2, R27.2, U9.1
unnamed: D9.C, R32.2
unnamed: D9.A, PWR1.1
unnamed: D12.C, U15.1
unnamed: R47.2, U15.5
unnamed: D12.A, R44.1
unnamed: D13.C, R45.2
unnamed: I2C2.3, R36.2
unnamed: I2C2.1, R37.2
unnamed: R33.2, U12.21
unnamed: C48.2, U12.20, Y3.P3
unnamed: C47.2, R33.1, Y3.P1
unnamed: J19.A5, R40.1
unnamed: J19.B5, R41.1
unnamed: C63.1, D11.C, Q3.2, R43.2, U14.1
unnamed: D14.C, R48.2
unnamed: D14.A, PWR2.1
unnamed: D17.C, U20.1
unnamed: R63.2, U20.5
unnamed: D17.A, R60.1
unnamed: D18.C, R61.2
unnamed: I2C3.3, R52.2
unnamed: I2C3.1, R53.2
unnamed: R49.2, U17.21
unnamed: C70.2, U17.20, Y4.P3
unnamed: C69.2, R49.1, Y4.P1
unnamed: J27.A5, R56.1
unnamed: J27.B5, R57.1
unnamed: C85.1, D16.C, Q4.2, R59.2, U19.1
unnamed: D19.C, R64.2
unnamed: D19.A, PWR3.1
unnamed: D22.C, U25.1
unnamed: R79.2, U25.5
unnamed: D22.A, R76.1
unnamed: D23.C, R77.2
unnamed: I2C4.3, R68.2
unnamed: I2C4.1, R69.2
unnamed: R65.2, U22.21
unnamed: C92.2, U22.20, Y5.P3
unnamed: C91.2, R65.1, Y5.P1
unnamed: J35.A5, R72.1
unnamed: J35.B5, R73.1
unnamed: C107.1, D21.C, Q5.2, R75.2, U24.1
unnamed: D24.C, R80.2
unnamed: D24.A, PWR4.1
QSPI-0: U4.5, U5.53
QSPI-1: U4.2, U5.55
QSPI-2: U4.3, U5.54
QSPI-3: U4.7, U5.51
QSPI-4: U1.5, U6.53
QSPI-5: U1.7, U6.51
QSPI-6: U1.2, U6.55
QSPI-7: U1.3, U6.54
QSPI-8: U11.5, U12.53
QSPI-9: U11.7, U12.51
QSPI-10: U11.2, U12.55
QSPI-11: U11.3, U12.54
QSPI-12: U16.5, U17.53
QSPI-13: U16.7, U17.51
QSPI-14: U16.2, U17.55
QSPI-15: U16.3, U17.54
QSPI-16: U21.5, U22.53
QSPI-17: U21.7, U22.51
QSPI-18: U21.2, U22.55
QSPI-19: U21.3, U22.54
QSPI-CLK: U4.6, U5.52
QSPI-CLK1: U1.6, U6.52
QSPI-CLK2: U11.6, U12.52
QSPI-CLK3: U16.6, U17.52
QSPI-CLK4: U21.6, U22.52
SDIO_DAT1: J6.8, U5.14
SDIO_DAT2: J6.1, U5.13
SDIO_DAT3: J12.8, U6.14
SDIO_DAT4: J12.1, U6.13
SDIO_DAT5: J20.8, U12.14
SDIO_DAT6: J20.1, U12.13
SDIO_DAT7: J28.8, U17.14
SDIO_DAT8: J28.1, U17.13
SDIO_DAT9: J36.8, U22.14
SDIO_DAT10: J36.1, U22.13
SPI0_CIPO: J7.13, J9.5, U5.6
SPI0_CIPO1: J13.13, J16.5, U6.6
SPI0_CIPO2: J21.13, J24.5, U12.6
SPI0_CIPO3: J29.13, J32.5, U17.6
SPI0_CIPO4: J37.13, J40.5, U22.6
SPI0_COPI: J7.12, J9.6, U5.5
SPI0_COPI1: J13.12, J16.6, U6.5
SPI0_COPI2: J21.12, J24.6, U12.5
SPI0_COPI3: J29.12, J32.6, U17.5
SPI0_COPI4: J37.12, J40.6, U22.5
SPI0_SCK: J7.11, J9.4, U5.4
SPI0_SCK1: J13.11, J16.4, U6.4
SPI0_SCK2: J21.11, J24.4, U12.4
SPI0_SCK3: J29.11, J32.4, U17.4
SPI0_SCK4: J37.11, J40.4, U22.4
SPI_!CS1!/SDIO_DAT1: J12.2, U6.12
SPI_!CS1!/SDIO_DAT2: J20.2, U12.12
SPI_!CS1!/SDIO_DAT3: J6.2, U5.12
SPI_!CS1!/SDIO_DAT4: J28.2, U17.12
SPI_!CS1!/SDIO_DAT5: J36.2, U22.12
SPI_CIPO1/SDIO_DAT0: J6.7, U5.15
SPI_CIPO1/SDIO_DAT1: J12.7, U6.15
SPI_CIPO1/SDIO_DAT2: J20.7, U12.15
SPI_CIPO1/SDIO_DAT3: J28.7, U17.15
SPI_CIPO1/SDIO_DAT4: J36.7, U22.15
SPI_COPI1/SDIO_CMD: J6.3, U5.18
SPI_COPI1/SDIO_CMD1: J12.3, U6.18
SPI_COPI1/SDIO_CMD2: J20.3, U12.18
SPI_COPI1/SDIO_CMD3: J28.3, U17.18
SPI_COPI1/SDIO_CMD4: J36.3, U22.18
SPI_SCK1/SDIO_CLK: J6.5, U5.17
SPI_SCK1/SDIO_CLK1: J12.5, U6.17
SPI_SCK1/SDIO_CLK2: J20.5, U12.17
SPI_SCK1/SDIO_CLK3: J28.5, U17.17
SPI_SCK1/SDIO_CLK4: J36.5, U22.17
SWDCK: J1.4, TP1.1, U5.24
SWDCK1: J15.4, TP4.1, U6.24
SWDCK2: J23.4, TP7.1, U12.24
SWDCK3: J31.4, TP10.1, U17.24
SWDCK4: J39.4, TP13.1, U22.24
SWDIO: J1.2, TP2.1, U5.25
SWDIO1: J15.2, TP5.1, U6.25
SWDIO2: J23.2, TP8.1, U12.25
SWDIO3: J31.2, TP11.1, U17.25
SWDIO4: J39.2, TP14.1, U22.25
UART0_RX: J7.14, J9.14, U5.3
UART0_RX1: J13.14, J16.14, U6.3
UART0_RX2: J21.14, J24.14, U12.3
UART0_RX3: J29.14, J32.14, U17.3
UART0_RX4: J37.14, J40.14, U22.3
UART0_TX: J7.15, J9.13, U5.2
UART0_TX1: J13.15, J16.13, U6.2
UART0_TX2: J21.15, J24.13, U12.2
UART0_TX3: J29.15, J32.13, U17.2
UART0_TX4: J37.15, J40.13, U22.2
USB_F_N: R12.2, U5.46
USB_F_N1: R18.2, U6.46
USB_F_N2: R34.2, U12.46
USB_F_N3: R50.2, U17.46
USB_F_N4: R66.2, U22.46
USB_F_P: R13.2, U5.47
USB_F_P1: R19.2, U6.47
USB_F_P2: R35.2, U12.47
USB_F_P3: R51.2, U17.47
USB_F_P4: R67.2, U22.47
USB_N: J5.A7, J5.B7, R12.1
USB_N1: J11.A7, J11.B7, R18.1
USB_N2: J19.A7, J19.B7, R34.1
USB_N3: J27.A7, J27.B7, R50.1
USB_N4: J35.A7, J35.B7, R66.1
USB_P: J5.A6, J5.B6, R13.1
USB_P1: J11.A6, J11.B6, R19.1
USB_P2: J19.A6, J19.B6, R35.1
USB_P3: J27.A6, J27.B6, R51.1
USB_P4: J35.A6, J35.B6, R67.1
V_BATT: C1.1, C10.1, J4.2, J8.1, Q1.3, U2.2, U2.3, U3.3
V_BATT1: C38.1, C44.1, J10.2, J14.1, Q2.3, U8.2, U8.3, U10.3
V_BATT2: C60.1, C66.1, J18.2, J22.1, Q3.3, U13.2, U13.3, U15.3
V_BATT3: C82.1, C88.1, J26.2, J30.1, Q4.3, U18.2, U18.3, U20.3
V_BATT4: C104.1, C110.1, J34.2, J38.1, Q5.3, U23.2, U23.3, U25.3
V_USB: C7.1, D2.A, J5.VBUS1, J5.VBUS2, J8.3, J9.10, Q1.1, R2.2, R15.2, U3.4
V_USB1: C43.1, D6.A, J11.VBUS1, J11.VBUS2, J14.3, J16.10, Q2.1, R26.2, R28.2, U10.4
V_USB2: C65.1, D11.A, J19.VBUS1, J19.VBUS2, J22.3, J24.10, Q3.1, R42.2, R44.2, U15.4
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

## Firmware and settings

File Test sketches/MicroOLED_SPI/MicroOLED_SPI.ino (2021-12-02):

/******************************************************************************
  MicroOLED_Hello.ino
  SFE_MicroOLED Hello World Demo
  Jim Lindblom @ SparkFun Electronics
  Original Creation Date: October 26, 2014
  
  This sketch lights up a familiar pattern on the MicroOLED
  Breakout. It's a great way to prove you've connected everything
  correctly and that your display is in working order.
  
  Hardware Connections:
    We'll be using the SPI interface on the MicroOLED, though it
    also supports I2C (and a really messy parallel). If you want
    to swap in I2C, read through the comments to find out how.
    
    MicroOLED ------------- Arduino
      GND ------------------- GND
      VDD ------------------- 3.3V (VCC)
    D1/MOSI ----------------- D11 (don't change)
    D0/SCK ------------------ D13 (don't change)
      D2
      D/C ------------------- D8 (can be any digital pin)
      RST ------------------- D9 (can be any digital pin)
      CS  ------------------- D10 (can be any digital pin)
    
  Development environment specifics:
  	IDE: Arduino 1.0.5
  	Hardware Platform: MicroOLED Breakout
                           Arduino Pro 3.3V/8MHz
  
  Note: The display on the MicroOLED is a 1.8V-3.3V device only.
  Don't try to connect a 5V Arduino directly to it! Use level
  shifters in between the data signals if you have to resort to
  a 5V board.
  
  This code is beerware; if you see me (or any other SparkFun 
  employee) at the local, and you've found our code helpful, 
  please buy us a round!
  
  Distributed as-is; no warranty is given.
*******************************************************************************/
#include <Wire.h>  // Include Wire if you're using I2C
#include <SPI.h>  // Include SPI if you're using SPI
#include <SFE_MicroOLED.h>  // Include the SFE_MicroOLED library

//////////////////////////
// MicroOLED Definition //
//////////////////////////
#define PIN_RESET 17  // Connect RST to pin INT on the mikroBUS socket
#define PIN_DC    16  // Connect DC to pin PWM on the mikroBUS socket
#define PIN_CS    5 // Connect CS to pin CS on the mikroBUS socket
#define DC_JUMPER 0 // Set to either 0 (default) or 1 based on jumper, matching the value of the DC Jumper
// Also connect pin 13 to SCK and pin 11 to MOSI

//////////////////////////////////
// MicroOLED Object Declaration //
//////////////////////////////////
// Declare a MicroOLED object. The parameters include:
// 1 - Reset pin: Any digital pin
// 2 - D/C pin: Any digital pin (SPI mode only)
// 3 - CS pin: Any digital pin (SPI mode only, 10 recommended)

MicroOLED oled(PIN_RESET, PIN_DC, PIN_CS); //Example SPI declaration, comment out if using I2C
//MicroOLED oled(PIN_RESET, DC_JUMPER); //Example I2C declaration, uncomment if using I2C 

// I2C is great, but will result in a much slower update rate. The
// slower framerate may be a worthwhile tradeoff, if you need more
// pins, though.
void setup()
{

  delay(100);
  //Wire.begin(); //set up I2C bus, uncomment if you are using I2C
  // These three lines of code are all you need to initialize the
  // OLED and print the splash screen.
  
  // Before you can start using the OLED, call begin() to init
  // all of the pins and configure the OLED.
  oled.begin();
  // clear(ALL) will clear out the OLED's graphic memory.
  // clear(PAGE) will clear the Arduino's display buffer.
  oled.clear(ALL);  // Clear the display's memory (gets rid of artifacts)
  // To actually draw anything on the display, you must call the
  // display() function. 
  oled.display();   
}

void loop()
{
}

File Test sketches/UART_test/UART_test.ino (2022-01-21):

void setup() {
  Serial.begin(115200);
  Serial1.begin(115200);

  //Serial.write("Hello world");
  Serial.print("Hello world");
}

void loop() {
  // put your main code here, to run repeatedly:
  Serial.println("Hello world");
  Serial.write("Hello world");
  Serial1.write("Hello world");
  delay(3000);
}

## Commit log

2021-09-14 Initial commit
    Starting with the MicroMod Qwiic Carrier - Single files.
    [MM-Qwiic-Carrier-Single.brd, MM-Qwiic-Carrier-Single.sch]
2021-09-23 Added mikroBUS socket to design
    [MM-Qwiic-Carrier-Single.brd, MM-Qwiic-Carrier-Single.sch, RP2040_Thing_Plus.brd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]
2021-09-27 Rename eagle files
    Make sure everything is connected in the schematic
    Parts are laid out where they should be on board, need to just route/re-route.
    [RP2040_MikroBUS.brd, RP2040_MikroBUS.sch]
2021-09-28 Routing finished!
    [RP2040_MikroBUS.brd, RP2040_MikroBUS.sch]
2021-09-28 Made board dimensions on grid
    [RP2040_MikroBUS.brd, RP2040_MikroBUS.sch]
2021-09-28 Space pins for thing plus shields
    [RP2040_MikroBUS.brd]
2021-09-30 Design review
    [RP2040_MikroBUS.brd, RP2040_MikroBUS.sch]
2021-09-30 Add raspi logos to repo
    [RP2040_MikroBUS.brd]
2021-09-30 More of Pete's updates
    * Fix I2C jumper label
    * Update RP2040 logo and add to SF Eagle libraries
    * Change "Mik" to "Mikro" for mikroBUS reset button
    [RP2040_MikroBUS.brd, RP2040_MikroBUS.sch]
2021-09-30 Schematic updates
    * Remove values from TPs
    * Updated net labels with "!" for active low signals - !BOOT!, !SPI0_CS!, !QSPI-CS!, !BATT_ALERT!
    * Updated name, value, and shape of mikroBUS socket sch symbol
    * Switched out SD card socket for the new one, did NOT connect the detect pin
    [RP2040_MikroBUS.brd, RP2040_MikroBUS.sch]
2021-09-30 Board updates
    * Fix RESET button label
    * Add RP2040 to SF microcontroller library and update in sch/board
    * Gave some more space between the new traces I placed
    * Brought D+ and D- traces closer together
    * Changed "WS2812" label to text only
    [RP2040_MikroBUS.brd, RP2040_MikroBUS.sch]
2021-09-30 Run checklist
    [RP2040_MikroBUS.brd, RP2040_MikroBUS.sch]
2021-10-28 MikroE updates
    * Change button label from "Mik Reset" to "Mikroe Reset"
    * Added mikroBUS pin names
    [RP2040_MikroBUS.brd, RP2040_MikroBUS.sch]
2021-11-05 Design review before ordering changes
    * Add a pullup and NC jumper on the CS line
    * A jumper on the PWR LED
    [RP2040_MikroBUS.brd, RP2040_MikroBUS.sch]
2021-11-05 Update silk screen labels and generate gerbers
    [RP2040_MikroBUS.GBL, RP2040_MikroBUS.GBO, RP2040_MikroBUS.GBP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]
2021-12-02 From MikroE convo
    * Remove mikroe button
    * Remove CS pullup
2021-12-11 Update labels
    [RP2040_MikroBUS.brd, RP2040_MikroBUS.sch]
2021-12-13 From mikroE convo
    * Remove reset button
    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
    [RP2040_MikroBUS.brd, RP2040_MikroBUS.sch]
2021-12-13 Design review updates
    * Bump version number
    * Remove CS_PU label from borrom
    * Move SWDCK TP
    [RP2040_MikroBUS.brd, RP2040_MikroBUS.sch]
2021-12-15 QC Double check
    * Added label for PWR jumper
    * Moved GPIO16 via
    [RP2040_MikroBUS.brd, RP2040_MikroBUS.sch]
2021-12-15 Run panelizer and generate gerbers
    [RP2040_MikroBUS-Panel.GBL, RP2040_MikroBUS-Panel.GBO, RP2040_MikroBUS-Panel.GBP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]
2022-01-25 Update RP2040_MikroBUS.brd
    Add dimensions to measurement layer
    [RP2040_MikroBUS.brd]
2022-01-25 Update RP2040_MikroBUS.brd
    Move text away from measurements area
    [RP2040_MikroBUS.brd]

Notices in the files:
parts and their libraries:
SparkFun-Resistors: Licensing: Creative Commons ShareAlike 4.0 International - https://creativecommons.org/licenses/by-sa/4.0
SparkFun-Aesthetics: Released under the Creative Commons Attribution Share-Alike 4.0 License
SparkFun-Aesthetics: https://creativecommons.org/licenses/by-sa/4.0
